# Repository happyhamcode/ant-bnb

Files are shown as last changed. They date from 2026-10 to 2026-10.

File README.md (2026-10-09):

# Ant BnB

**A spill-proof stay for liquid ant bait.** Ants check in, the bait stays put.

A 3D-printable enclosure for [Terro T300 liquid ant bait stations](https://www.amazon.com/TERRO-T300-2-2-Pack-Liquid-Baits/dp/B00E4GACB8).
The bait containers are easy to knock over and spill, which makes a sticky mess and defeats the point. This
box holds the container upright, lets ants in, and keeps spills inside. It is meant for floors and countertops.

<p align="center">
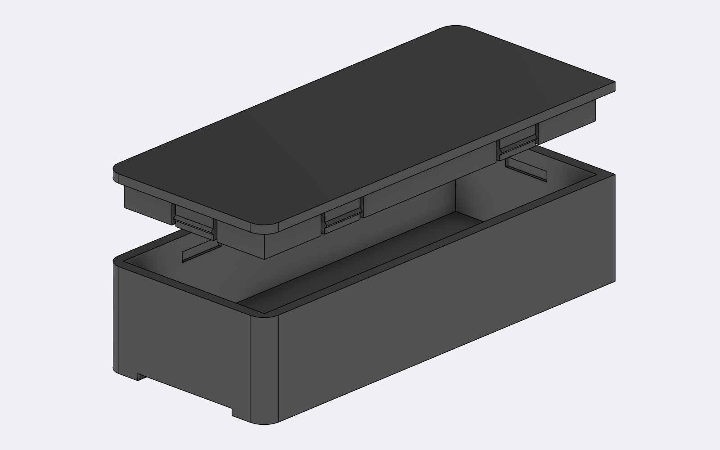
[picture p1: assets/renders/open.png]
Render of the box with the lid lifted off
  
</p>

<p align="center">
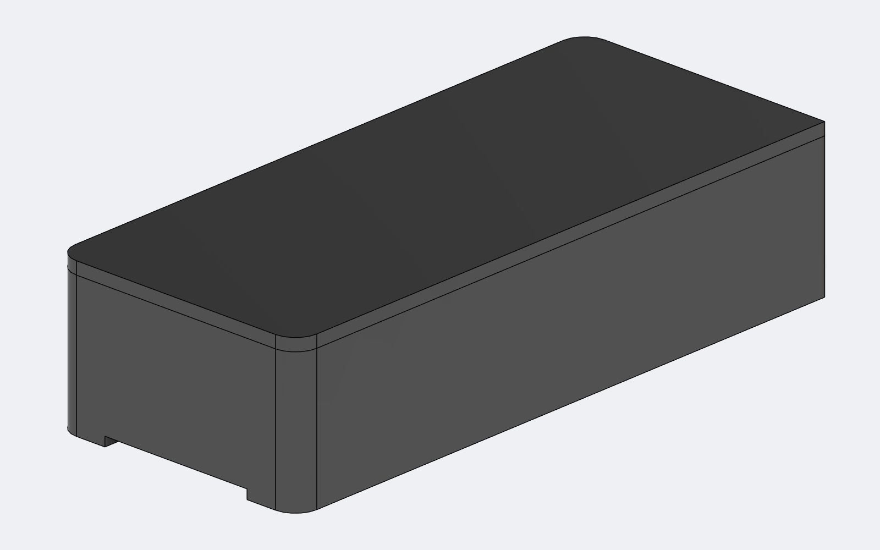
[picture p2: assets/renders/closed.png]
Closed box
  
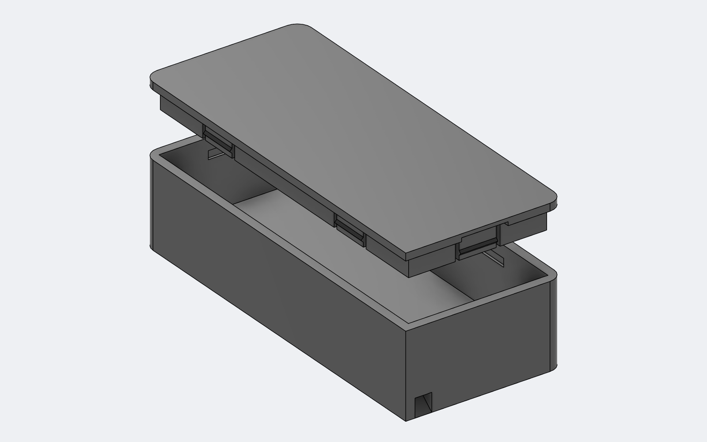
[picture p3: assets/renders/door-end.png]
Ant door end
  
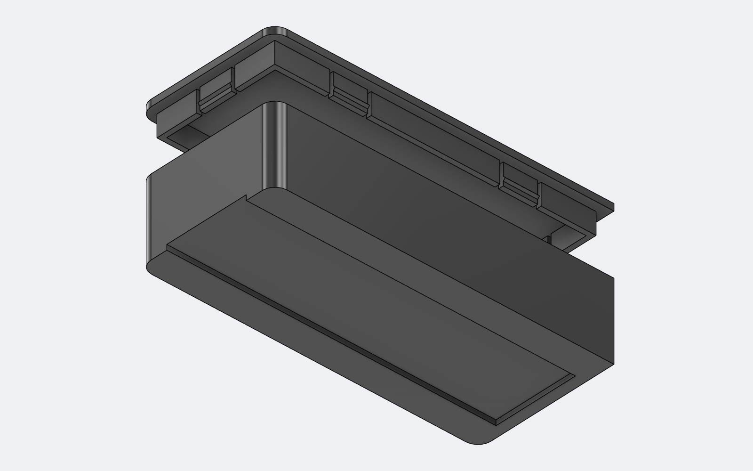
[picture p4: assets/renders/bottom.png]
Underside with the command strip recess
  
</p>

<p align="center"><em>Lid lifted off, closed, the ant door end, and the underside with the command strip recess.</em></p>

## Available at these major retailers

Get the Terro T300 liquid ant baits here:

<p>
  <a href="https://www.amazon.com/TERRO-T300-2-2-Pack-Liquid-Baits/dp/B00E4GACB8">Amazon</a>
  &nbsp;&nbsp;&nbsp;
  <a href="https://www.homedepot.com/p/TERRO-Indoor-Liquid-Ant-Killer-Baits-6-Count-T300/202532940">The Home Depot</a>
  &nbsp;&nbsp;&nbsp;
  <a href="https://www.lowes.com/pd/TERRO-6-Count-Ant-Bait-Station-6-Pack/5001954631">Lowe's</a>
</p>

_Pack sizes, prices and stock vary by store. Amazon, The Home Depot and Lowe's names and logos are trademarks of their owners and are used only to link to the product._

## Features

- **Fits the Terro T300 station** with its twist top removed (4.15 in overall, about 3.65 in without the top, 1.305 in wide,
  0.44 in tall): 3.750 x 1.500 x 0.750 in interior (3.950 x 1.700 x 0.900 in outside).
- **Ants in, spills out**: a ground-level door leads to a walled ramp that climbs over a spill dam before dropping into
  the tray. Liquid has to rise 0.25 in (about 23 mL, far more than a container holds) to reach the door.
- **Snap-fit lid**: flex fingers with wedge bumps click into grooves in the walls. A coin slot lets you pry it open;
  a paw can't.
- **Command strip recess**: a pocket in the bottom takes a medium or large 3M Command strip so it can stay put.
  The recess is open at the end opposite the ramp so the strip's pull tab sticks out for easy removal.

## Print it

1. Open `anttrap_v2_A1mini.3mf`: a base and lid pair already laid out for a Bambu Lab A1 mini plate.
2. Or use `anttrap_base.3mf` and `anttrap_lid.3mf` (inches) for any other printer. The lid is flipped plate-down so
   it needs no supports.
3. PLA or PETG both work. No supports needed.

If the lid is too tight or loose, change `c` (snap clearance, default 0.008 in) or `p` (bump height, default
0.025 in) in `fusion_box_build.py` and re-export.

## Rebuild or change it

`fusion_box_build.py` builds the whole model in Fusion 360 through the Fusion API. All dimensions are
parameters at the top of the script, so changing the interior size, wall thickness or door size resizes everything.
Run it in an empty design.

The original v1 (for the full 4.15 in T300 with the top on) is an Onshape FeatureScript, `anttrap_shell.fs`. See `handover.md` for
design notes and `fusion360_conversion.md` for the build spec.

## Files

| File | What |
|---|---|
| `anttrap_v2_A1mini.3mf` | Slicer project, base + lid pair for a Bambu Lab A1 mini |
| `anttrap_base.3mf`, `anttrap_lid.3mf` | Print-ready parts (inches) |
| `assets/logos/` | Retailer logos used in this README |
| `fusion_box_build.py` | v2 parametric Fusion 360 build script |
| `anttrap_shell.fs` | v1 Onshape FeatureScript (Terro T300) |
| `handover.md`, `fusion360_conversion.md` | Design notes and build spec |

Ant BnB is an independent project and a joke name. It isn't affiliated with or endorsed by Terro or Airbnb.

## License

Copyright (c) 2026 Happy Ham. Licensed under
[Creative Commons Attribution-NonCommercial-ShareAlike 4.0 International (CC BY-NC-SA 4.0)](https://creativecommons.org/licenses/by-nc-sa/4.0/).
You can print, share and remix it for non-commercial use, as long as you credit this project and share your
changes under the same license. See [LICENSE](LICENSE).

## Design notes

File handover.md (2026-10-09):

# Ant BnB: handover

## What this is

One file: `anttrap_shell.fs`. It is an **Onshape FeatureScript** (std version 3083) that generates a
pet-safe, 3D-printable enclosure for a **TERRO T300 liquid ant bait station** (measured 4.150 x 1.305 x 0.440 in).

It is a parametric custom feature named **"Ant Trap Shell"**. Every dimension derives from the
measured station size, so changing one input resizes the whole trap.

## How it works (what you get when it regenerates)

- **Base tray**: floor on z = 0, walls, open top. Outer size is computed: station + clearance + ant alley + walls.
- **Corner stops**: four L-shaped posts that locate the station so it can't slide.
- **Corner door + stairwell** at the +X end: ants enter at ground level, climb a walled stair over a
  **spill dam**, then drop into the tray. Liquid can't reach the door until it tops the dam.
  The entry corner is left square so the trap can sit flush against a wall.
- **Snap-fit lid**: six flex fingers with wedge bumps click into grooves in the base walls
  (same design as the cyberdeck cover). A **coin slot** on the +X end lets a flat blade pry it open; a paw can't.
- **Screw-down ears** on both short ends (optional).
- **Floor-level entry slots** exist but are **off by default** because they leak.

## Code map (`anttrap_shell.fs`)

| Lines | What |
|---|---|
| 13-36 | `LB_*` / `AB_*` bound specs: min / default / max for each UI input |
| 38-54 | Fixed constants: snap lip/finger/bump sizes, corner stop size, dam thickness, coin slot |
| 56-97 | `cutBox` / `addBox`: axis-aligned box subtract / union helpers (used everywhere) |
| 99-161 | Wall-side helpers (side 0 = y=0, 1 = y=W, 2 = x=0, 3 = x=L), `snapSites`, `slotSites` |
| 163-194 | Fillet helpers (vertical corners, lid top perimeter) |
| 196-234 | `addEar` |
| 236-326 | `antTrapShell` feature UI: the parameter list |
| 328-363 | Derived dimensions + sanity checks (`regenError` messages) |
| 364-423 | Base body, cavity, slots, corner stops, ears |
| 425-448 | Door, stair, dam |
| 450-534 | Lid: grooves, plate, lip, snap fingers, coin slot, fillets, display offset |
| 536-566 | Default values (must match the `LB_*` defaults) |

## Working on another computer

There is no local build. The file only runs inside Onshape.

1. `git clone https://github.com/happyhamcode/ant-bnb.git`.
2. In Onshape: open a Part Studio's document, **+ > Feature Studio**, name it e.g. `anttrap`.
3. Paste the whole contents of `anttrap_shell.fs` over the default text. Onshape compiles on paste.
4. In a Part Studio in the same document, click the feature toolbar's **Ant Trap Shell** (it appears under custom features).
5. Edit the code in the Feature Studio, or edit locally and re-paste. Then **copy the final text back into the repo file**.
6. `git add -A && git commit -m "..." && git push`.

Onshape is the source of truth while you iterate; the repo file is only the saved copy. Always paste back before committing.

## How to adjust (v2 starting points)

- **Station is a different size**: change the defaults in the last block (lines 537-540), and the
  bound defaults at 13-16 if you want the UI slider to match.
- **Add or rename an input**: three places must agree: the `LB_*` bound (13-36), the `annotation` +
  `isLength` / boolean in the precondition (236-326), and the default map (536-566). Missing any one gives a compile error.
- **Entry door**: `entryWidth`, `entryHeight`, `entrySill` (dam height), `rampAngle`, `entryOnPlusY` (flip corner).
  The `regenError` checks at 342-357 tell you when a combination doesn't fit; read them before changing these.
- **Snap fit too tight / loose**: `snapClearance` (default 0.008 in) and `snapBump` (0.025 in). Print-tolerance dependent: expect to tune per printer.
- **Snap finger count or positions**: `snapSites` (line 144). Coin slot position: line 526.
- **Fixed geometry** (lip height, finger width, stop size, dam thickness) is a plain constant at lines 39-54, not a UI input. Promote it to an input using the three-place rule above.

## Known caveats

- **Not yet printed or tested** as far as this repo records. Treat clearance values as unverified.
  The comment at line 8 says station clearance is generous because the stations are mass-molded and vary.
- Floor slots are a leak path. Leave `buildFloorSlots` off unless you add a sill (`slotSill`) and accept the risk.
- Lid-lip vs. slot and stair-vs-rim collisions throw `regenError`; this is intended, not a bug.
- The stairwell must fit in the side alley: `entryWidth + dam (0.06 in) <= alley + clearance`.
  Widening the door means widening `alley`.
- Bump/groove geometry uses a rotated sketch plane per wall side (lines 507-516). Easiest place to introduce a sign error if you change wall sides.

## Fusion 360

The v2 will be built in Fusion 360. See `fusion360_conversion.md` for parameters, build order and computed coordinates.

## Repo

`https://github.com/happyhamcode/ant-bnb` (public), branch `main`.

## v2: Fusion 360 build (this is the current design)

v2 is a smaller trap for the TERRO T300 with its twist top removed (about 3.65 in long instead of 4.15 in overall),
built in Fusion 360 by script.
The v1 Onshape FeatureScript above is kept for reference.

- **Ready to slice**: `anttrap_v2_A1mini.3mf` is a slicer project with a base and lid pair laid out on a Bambu Lab A1 mini plate.
- **Files**: `fusion_box_build.py` (Fusion API script, all parameters at the top), `anttrap_base.3mf` and
  `anttrap_lid.3mf` (print-ready, inches, lid already flipped plate-down).
- **Interior**: 3.750 x 1.500 x 0.750 in. Walls 0.10, floor 0.15. Outer 3.950 x 1.700 x 0.900 in.
- **Command strip recess** in the bottom: 3.70 x 1.00 x 0.06 in, open through the -X end (opposite the ramp)
  so the strip's pull tab sticks out the back for removal.
- **Ant door + ramp + spill dam** at the +X end, -Y corner (carried over from v1). The floor is lowered in the
  stairwell so the ramp is one continuous 40 degree slope. Liquid must top the 0.25 in dam (~23 mL) to reach the door.
- **Snap-fit lid**: 6 flex fingers (2 per long wall, 1 per end) with wedge bumps into wall grooves, plus a coin slot.
  Same snap values as v1 (clearance 0.008 in, bump 0.025 in), which printed and worked fine. The v2 lid is smaller, so if it
  feels too tight, drop the bump (`p` in the script) to 0.02 in.
- Dropped from v1: corner stops, screw ears, floor slots (container size unknown, countertop use only).
- Orientation: floor on the XY plane (z = 0), +Z up, so a Y-up Fusion document shows it lying back.

### Rebuilding in Fusion
Fusion MCP server must be running (it listens on `127.0.0.1:27182/mcp`). Run `fusion_box_build.py` in an empty
design with the Fusion API (it defines `run(_context)`), or paste it into Scripts and Add-Ins.

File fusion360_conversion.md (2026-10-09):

# Fusion 360 conversion spec

Source: `anttrap_shell.fs` (Onshape FeatureScript). This file gives everything needed to rebuild the
model in Fusion 360 by hand, with all derived numbers already computed for the default inputs.
Line references (`fs:NNN`) point into `anttrap_shell.fs`.

## 0. Setup (do first)

1. **Z-up**: Preferences > General > Default modeling orientation > **Z up**. The script is Z-up
   (floor on z = 0, lid above). Skipping this mirrors every Y/Z instruction below.
2. **Units**: set document units to **inch**. Fusion stores cm internally; type `in` in fields if unsure.
3. **Origin** = outer bottom corner of the base at (0, 0, 0). Base occupies **x 0..L, y 0..W, z 0..H**.
   +X end = the end with the ant door and coin slot. The door sits at the **(x = L, y = 0)** corner.
4. Build as **one component for the base** and **one for the lid**. In the FeatureScript the lid is a
   second body in the same studio, shifted up by `lidOffset` for display. Model it seated (offset 0),
   then export base and lid separately for printing. Print lid **plate-down-flat** (top face on the bed is
   fine; flip it for printing and check overhang on the lip/bumps).

## 1. User Parameters (Modify > Change Parameters > +)

Create these, in order. Expressions can reference earlier ones.

| Name | Expression | Value (in) | Meaning |
|---|---|---|---|
| `stationL` | `4.15 in` | 4.150 | TERRO T300 length (X) |
| `stationW` | `1.305 in` | 1.305 | width (Y) |
| `stationH` | `0.44 in` | 0.440 | height (Z) |
| `clr` | `0.063 in` | 0.063 | clearance per side (mass-molded, varies) |
| `alley` | `0.25 in` | 0.250 | ant gap, station to wall |
| `headroom` | `0.245 in` | 0.245 | gap above station |
| `t` | `0.1 in` | 0.100 | wall thickness |
| `f` | `0.08 in` | 0.080 | floor thickness |
| `cornerR` | `0.15 in` | 0.150 | vertical outer corner radius |
| `topFillet` | `0.05 in` | 0.050 | lid top edge fillet |
| `stopH` | `0.15 in` | 0.150 | corner stop height above floor |
| `entryW` | `0.18 in` | 0.180 | door and stairwell width |
| `entryH` | `0.2 in` | 0.200 | door height above ground |
| `entrySill` | `0.25 in` | 0.250 | stair top above inside floor (dam height) |
| `rampAng` | `40 deg` | 40 | stair angle |
| `plateT` | `0.08 in` | 0.080 | lid plate thickness |
| `snapC` | `0.008 in` | 0.008 | lip-to-wall snap clearance |
| `snapP` | `0.025 in` | 0.025 | snap bump height |
| `earLen` | `0.4 in` | 0.400 | ear length past wall |
| `earHole` | `0.17 in` | 0.170 | ear screw hole diameter |

Fixed constants (fs:39-54), also make these parameters so v2 can tweak them:

| Name | Expression | Value |
|---|---|---|
| `lipT` | `0.06 in` | lid lip wall thickness |
| `lipH` | `0.25 in` | lip drop below plate underside |
| `fingerW` | `0.4 in` | snap finger width |
| `reliefW` | `0.04 in` | relief slot beside each finger |
| `bumpH` | `0.07 in` | bump height along Z |
| `stopArm` | `0.2 in` | corner stop arm length |
| `stopT` | `0.06 in` | corner stop thickness |
| `damT` | `0.06 in` | dam wall thickness |
| `coinW` | `0.5 in` | coin slot width |
| `coinD` | `0.04 in` | coin slot depth |
| `earR` | `0.25 in` | ear radius (fs:420, hard-coded) |

Derived (user parameters too, so they update):

| Name | Expression | Default value |
|---|---|---|
| `pocketL` | `stationL + 2 * clr` | 4.276 |
| `pocketW` | `stationW + 2 * clr` | 1.431 |
| `L` | `pocketL + 2 * alley + 2 * t` | **4.976** |
| `W` | `pocketW + 2 * alley + 2 * t` | **2.131** |
| `H` | `f + stationH + headroom` | **0.765** |
| `entryTopZ` | `f + entrySill` | 0.330 (stair peak / dam top, absolute Z) |
| `peakX` | `L - entryTopZ / tan(rampAng)` | 4.583 |
| `footX` | `peakX - entrySill / tan(rampAng)` | 4.285 |

Note: `footX` uses `entrySill` (0.25), not `entryTopZ` (0.33). That is how the script is written (fs:350-351);
keep it unless you intentionally change the stair shape.

Pocket (where the station sits) spans x 0.35..4.626, y 0.35..1.781 (offset `t + alley` from each wall).

## 2. Base build order

All cuts below use "box" = sketch a rectangle on a plane at the stated Z, extrude. The script overshoots
cuts by **0.02 in** (`overcut`) so faces are not coplanar. Do the same: Fusion's boolean also fails on
coplanar faces.

1. **Outer block**: rectangle (0,0)-(L,W) on XY, extrude up `H`.
2. **Outer vertical corner fillets**, radius `cornerR`, on the four vertical edges, **except the (L, 0) edge**
   (kept square so the trap sits flush against a wall). If you build the door on +Y, skip (L, W) instead.
   Do this before step 3 (inner cavity corners stay square).
3. **Cavity**: cut rectangle (t, t)-(L-t, W-t) from the top down to z = f (leaves floor thickness `f`).
4. **Corner stops**, one L per pocket corner, z from f to f + stopH. For the corner at (cx, cy) with inward
   direction (dx, dy) (signs pointing into the pocket):

   | Corner (cx, cy) | dx, dy |
   |---|---|
   | (0.35, 0.35) | +1, +1 |
   | (4.626, 0.35) | -1, +1 |
   | (0.35, 1.781) | +1, -1 |
   | (4.626, 1.781) | -1, -1 |

   - **X arm**: x from `cx - dx*stopT` to `cx + dx*stopArm`; y from `cy` to `cy - dy*stopT` (outside pocket edge).
   - **Y arm**: x from `cx` to `cx - dx*stopT`; y from `cy` to `cy + dy*stopArm`.

   Each arm is a box; they overlap at the corner and form an L hugging the station corner from outside.
5. **Ears (optional, `buildEars`)**: on the XY plane at z = 0, centered y = W/2, thickness `f + 0.04 = 0.12`.
   Profile = rectangle `2*earR` wide (0.5) plus a circle radius `earR` at the tip.
   - Ear A: rectangle from x = +0.05 (inside wall) to tip x = `-earLen`; tip center (-0.4, W/2).
   - Ear B: rectangle from x = L - 0.05 to tip x = `L + earLen`; tip center (L + 0.4, W/2).
   - Through hole dia `earHole` at each tip center.
6. **Door (`buildEntry`)**: cut box through the +X wall: x from L - t to L, y from `eY0` to `eY1`, z from 0 to `entryH`.
   - Default (-Y corner): `eY0 = t = 0.1`, `eY1 = eY0 + entryW = 0.28`.
   - `entryOnPlusY` (mirror about y = W/2): `eY0 = W - t - entryW`.
7. **Stair** (a tent-shaped ridge in the stairwell): sketch on the **XZ plane offset to y = eY0**. Closed polygon in (x, z):

   `(L, 0) -> (peakX, entryTopZ) -> (footX, f - 0.02) -> (footX, 0) -> (L, 0)`

   Default: (4.976, 0) -> (4.583, 0.330) -> (4.285, 0.060) -> (4.285, 0) -> back.
   Extrude **+Y by `entryW`** (from eY0 to eY1), join to the base. Ants walk in at the door at ground level,
   climb the up-slope to the peak, and drop onto the floor on the down-slope.
   For `entryOnPlusY`, extrude the same profile from `eY0` (= W - t - entryW) toward +Y as well (script does
   this in both cases; only `eY0` changes).
8. **Spill dam**: box x from `peakX` to `L - t + 0.02`; y from `damY0` to `damY0 + damT`;
   z from `f - 0.02` to `entryTopZ`. Default `damY0 = eY1 = 0.28` (dam y 0.28..0.34, just short of pocket at 0.35).
   For `entryOnPlusY`, `damY0 = eY0 - damT` (dam on the inner side of the stairwell).
   This wall stops liquid in the tray reaching the door until it tops `entryTopZ`.
9. **Snap grooves in base walls** (6 sites, see section 4). At each site, cut a box into the wall from its
   inner face outward by `grooveDepth = snapP - snapC + 0.01 = 0.027 in`:
   - Width along the wall: `fingerW + 0.04 = 0.44`, centered on the site.
   - Z: from `zb0 + bumpH + 0.01 - (bumpH + 0.02)` to `zb0 + bumpH + 0.01`, i.e. **z 0.545..0.635** with defaults,
     where `zb0 = H - lipH + 0.04 = 0.555`.

## 3. Lid build order

Seated position: plate underside at z = H. Build it in place, then you can leave it there or move it up for display.

1. **Plate**: rectangle (0,0)-(L,W) at z = H, extrude up `plateT` (z 0.765..0.845).
2. **Lip**: rectangle (t + snapC, t + snapC)-(L - t - snapC, W - t - snapC) = **(0.108, 0.108)-(4.868, 2.023)**,
   extruded from z = H + plateT/2 **down** to z = H - lipH (0.515). Join to the plate.
3. **Hollow the lip**: cut rectangle inset another `lipT` = **(0.168, 0.168)-(4.808, 1.963)** from z = H downward
   by `lipH + 0.02`. The plate underside stays flat at z = H. This leaves a 0.06 in thick lip.
4. **Snap fingers**, at each of the 6 sites (section 4), `a0 = pos - fingerW/2`, `a1 = pos + fingerW/2`:
   - **Relief slots**: two boxes through the lip thickness (across the lip) at `a0 - reliefW .. a0` and `a1 .. a1 + reliefW`,
     cut from z = H downward `lipH + 0.02`. This frees a 0.4 in wide cantilever finger hanging from the plate.
   - **Wedge bump**: triangle profile in the plane perpendicular to the wall, extruded **fingerW** along the wall from `a0`:
     - Base edge on the lip's **outer face** minus 0.01 in (slightly inside the lip so the union overlaps),
       from z = `zb0` (0.555) to `zb0 + bumpH` (0.625).
     - Apex = `snapP` (0.025) **outward of the lip outer face**, at z = `zb0 + bumpH/2` (0.590).
     - Outward = toward the nearest wall of the base (i.e., away from the box center).
     Join to the lid.
5. **Door notch in lid lip**: **only if** `entryH > H - lipH` (0.515). With defaults it is 0.2, so **skip**. If you raise the
   door above that, cut a box x `L - t - snapC - lipT .. L - t - snapC`, y `eY0..eY1`, z `H - lipH..H` from the lip.
6. **Coin slot**: box x `L - 0.12 .. L`, y `W/2 +/- coinW/2` (1.0655 +/- 0.25), z from `H` up to `H + coinD` (0.04).
   Removes plate material from the **underside** of the +X edge. A flat blade pries the lid up here; a paw can't.
   (The script's box actually starts 0.02 below H, trimming the top 0.02 of the lip; harmless, you can ignore it.)
7. **Lid fillets**: vertical corner fillet `cornerR` on the plate's four outer vertical edges (skip the same square
   corner as the base), then `topFillet` (0.05) on the top perimeter edges (tangent chain).
8. (Display only) shift the lid up `lidOffset` (0.5 in) so the interior is visible. Leave at 0 for printing.

## 4. Snap site table (default values)

Side 0 = wall at y = 0, side 1 = y = W, side 2 = x = 0, side 3 = x = L. "pos" is the coordinate along that wall.

| # | Wall | pos |
|---|---|---|
| 0 | y = 0 | x = 1.244 (`L * 0.25`) |
| 1 | y = 0 | x = 3.732 (`L * 0.75`) |
| 2 | y = W | x = 1.244 |
| 3 | y = W | x = 3.732 |
| 4 | x = 0 | y = 1.0655 (`W / 2`) |
| 5 | x = L | y = 1.0655 |

Site 5 (x = L) sits in the same wall as the door (y 0.1..0.28) and the coin slot (y 0.8..1.3). The finger
(y 0.8655..1.2655) overlaps the coin-slot y range. In the script the slot is only in the plate underside,
so both coexist. Keep that arrangement.

## 5. Optional features (off by default)

- **Floor-level entry slots** (`buildFloorSlots`): leak path, off by default, skip in the first Fusion build.
  Spec if needed (fs:154-161, 383-394): through-wall boxes `slotWidth` (0.25) wide, `slotHeight` (0.12) tall,
  bottom at `f + slotSill` (0.12). Sites: sides 0 and 1 at x = `L*0.12`, `L/2`, `L*0.88`; sides 2 and 3 at y = `W/2`.
- **Entry on +Y**: mirror the door, stairwell, dam, and square corner about y = W/2 (section 2 steps 2, 6-8).

## 6. Checks the script enforces (replace with Fusion parameter warnings or just check by eye)

| Check | Condition that **fails** (fs line) |
|---|---|
| Lid lip hits slots | slots on, lid on, and `H - lipH < slotTop + 0.05` (342) |
| Door too low for stair | `entryH < t * tan(rampAng) + 0.08` (352) |
| Stair top near rim | `entryTopZ > H - 0.05` (354) |
| Stairwell too wide | `entryW + damT > alley + clr` (356) |

Default design passes all four (0.2 >= 0.164; 0.33 <= 0.715; 0.24 <= 0.313).

## 7. Validation checklist after building

1. Base overall size = **4.976 x 2.131 x 0.765 in**; lid overall = 4.976 x 2.131 x 0.08 plate + lip below.
2. Station pocket = **4.276 x 1.431 in** clear, floor top at z = 0.08, corner stops reach z = 0.23.
3. Dam top and stair peak both at **z = 0.33**, below the rim at 0.765 and below the station top at 0.52.
4. Lid lip outer faces are **0.008 in** off the wall inner faces; bump apex is 0.017 in into the wall; groove is 0.027 in deep.
5. Lid seated: plate underside = base rim top (z = 0.765), no interference between the lip and the stair or corner stops
   (lip bottom z = 0.515 is above stop top 0.23 and dam top 0.33).

## 8. Known unverified items

- The Onshape model has not been printed or tested, per `handover.md`. Treat clearance values as starting points.
- Fusion has no direct equivalent of `regenError`; the checks in section 6 must be done manually.
- Fusion's default Y-up will silently turn Z measurements into Y measurements: do step 0.1.

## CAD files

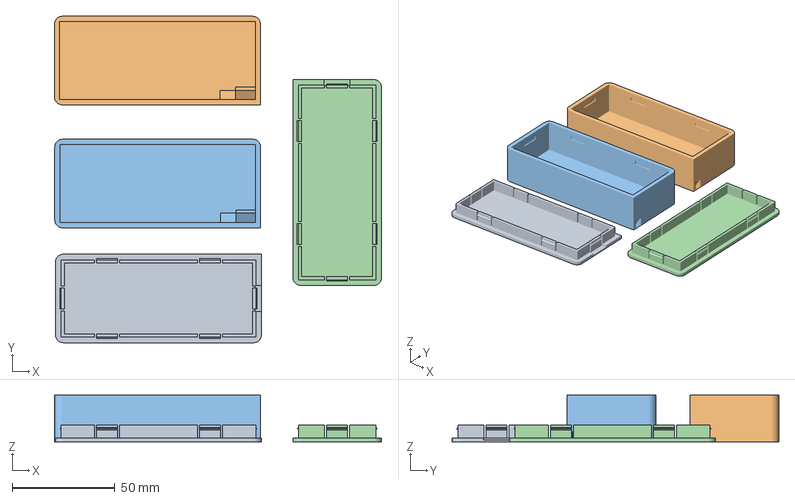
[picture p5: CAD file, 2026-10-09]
anttrap_v2_A1mini.3mf
159.3 x 159.1 x 22.9 mm
Lid x 2
Base x 2

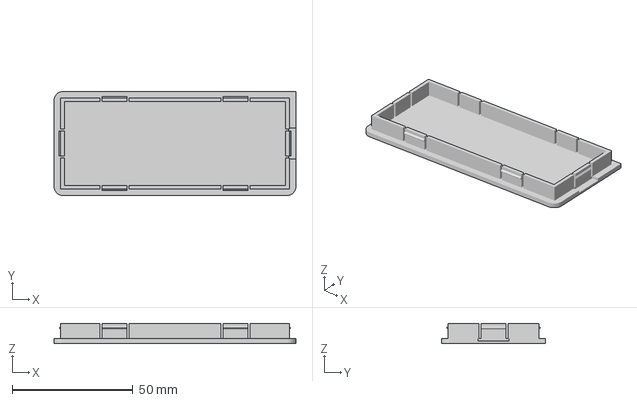
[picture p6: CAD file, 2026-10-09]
anttrap_lid.3mf
100.3 x 43.2 x 8.38 mm

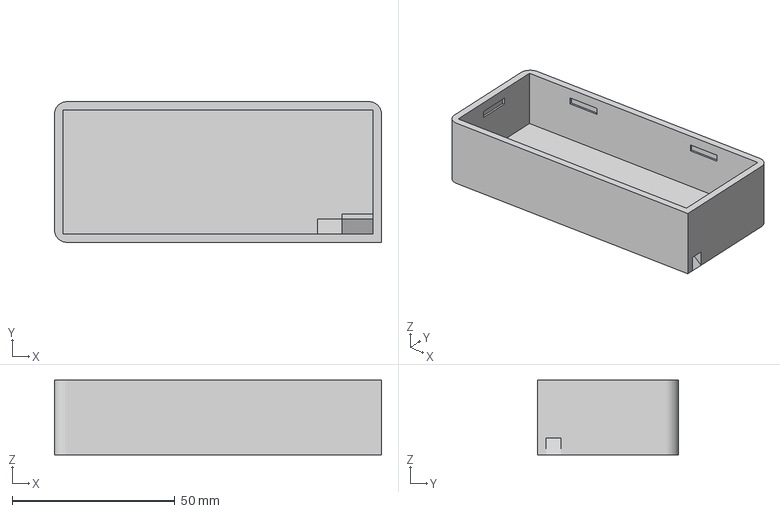
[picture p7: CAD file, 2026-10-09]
anttrap_base.3mf
100.3 x 43.2 x 22.9 mm

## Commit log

2026-10-09 v2: Fusion 360 box with 3.75x1.5x0.75 in interior, snap lid, strip recess
    Adds fusion_box_build.py (parametric Fusion API script), print-ready
    3MF files for base and lid, and a v2 section in handover.md.
    - Command strip recess in the bottom, open at the end opposite the ramp
    - Snap-fit lid with flex fingers, wedge bumps and wall grooves
    - Ramp floor lowered so the climb is one continuous slope
    [anttrap_base.3mf, anttrap_lid.3mf]
2026-10-09 Add A1 mini slicer project for the v2 box
    Base and lid pair laid out to fit a Bambu Lab A1 mini plate.
    [anttrap_v2_A1mini.3mf]
